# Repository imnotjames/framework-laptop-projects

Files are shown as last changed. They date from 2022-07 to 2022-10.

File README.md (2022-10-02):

# Framework Laptop projects

## eDP port

The framework laptop uses the [I-PEX Cabline-UM 20879-040E-01](https://www.i-pex.com/product/cabline-um)
for interacting with the eDP port - and I want to use it for things other than the framework laptop display kit.

* [Framework eDP 20879-040E-01 Breakout](./breakout/)

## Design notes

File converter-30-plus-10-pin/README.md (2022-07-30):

# Converter for Framework Laptop to 30+10pin 

This converts the framework laptop's 4 lane eDP to the 2 lane used in lower resolution screens.

In particular, this is aimed to allow us to easily interact with the [NV126B5M-N41][amazon] but it's not
exactly tested.

[amazon]: https://www.amazon.com/VSDISPLAY-NV126B5M-N41-12-6inch1920X515-Controller-VS-RTD2556HM-V1/dp/B08FJ33247

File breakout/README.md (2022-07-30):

# Cabline-UM Breakout Board

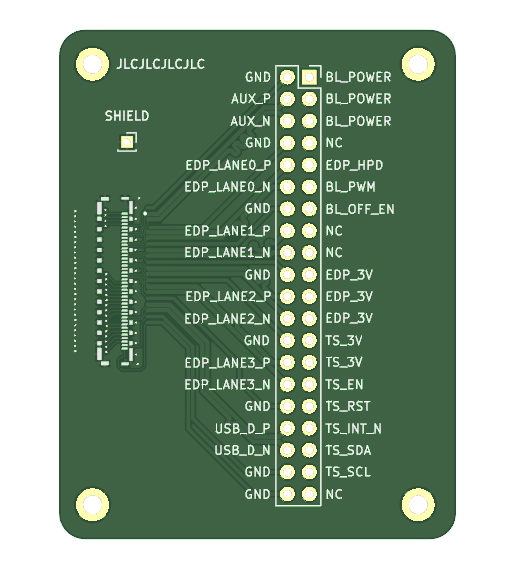
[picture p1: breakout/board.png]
The Breakout Board


This is a breakout board for the Framework Mainboard eDP connection via Cabline-UM 20879-040E-01.

This does not work with the standard Framework laptop cable that comes with the display kit.
The display kit seems to come with a cable that is on one half the cabline-um and on the other half is a cabline-vs
plug.

Instead, this breakout uses the Cabline-UM 20879-040E-01 to connect to the Framework mainboard, allowing you access
to all of the pins in a breakout.

Don't expect to be able to use it for reliable high-speed display-port connections but it may work for
basic prototypes or confirming the touchscreen.

## Fabrication

I've had decent luck getting this fabricated on JLCPCB - it was made with their limitations and tolerances in mind.

## Assembly Hints

If you can figure out how to assemble this by hand with a soldering iron please let me know how!  Most of the pins are hidden
behind a shield so the only way I was able to manage this was with a hot plate and solder paste.

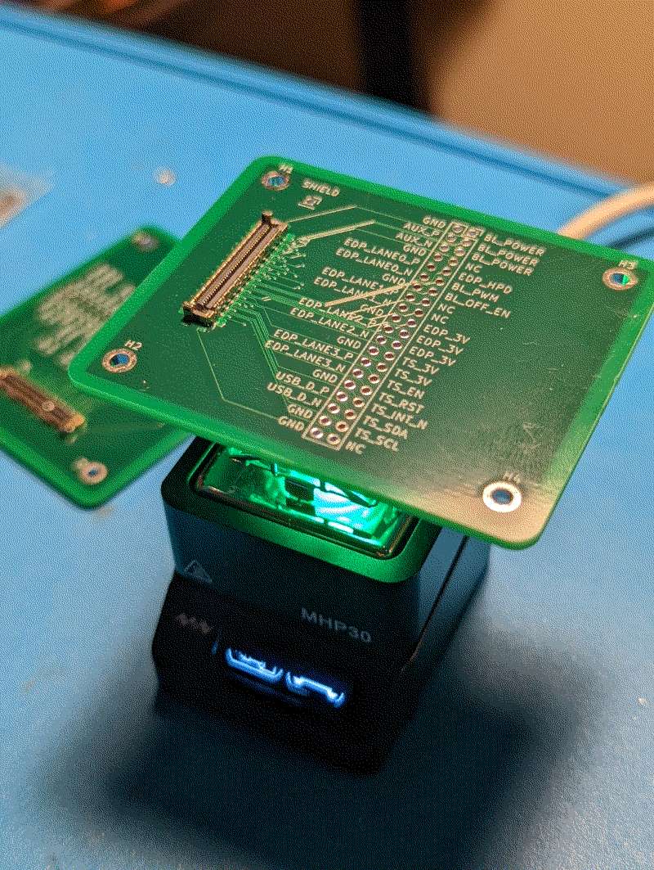
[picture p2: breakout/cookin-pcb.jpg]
Cookin' up some PCB


## Bill of Materials

* [I-PEX 20879-040E-01](https://www.digikey.com/en/products/detail/i-pex/20879-040E-01/14312094)
* [A 40 Position Header Connector with 2.54mm pitch](https://www.digikey.com/en/products/detail/sullins-connector-solutions/PPTC202LFBN-RC/807240)
* [A Cabline-UM plug such as the 81466-100B-02-D](https://www.digikey.com/en/products/detail/i-pex/81466-100B-02-D/14312108)

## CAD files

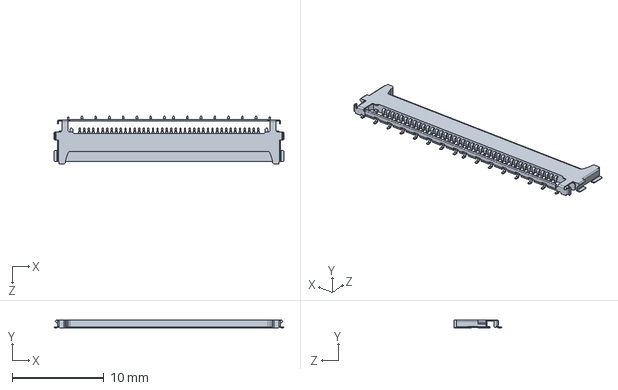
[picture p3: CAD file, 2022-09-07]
converter-30-plus-10-pin/pcb/footprints/20849-040E-01.step
25.1 x 0.82 x 5.20 mm

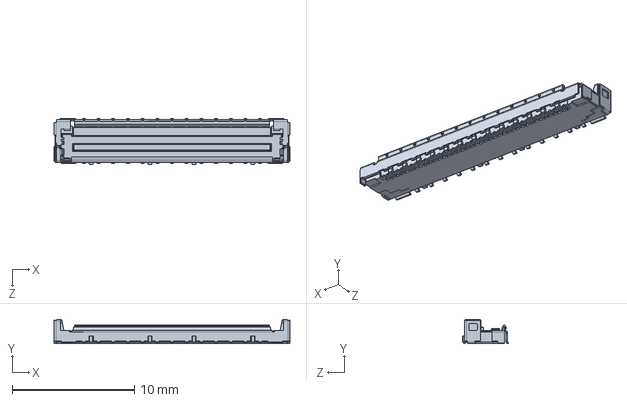
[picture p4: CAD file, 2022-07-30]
converter-30-plus-10-pin/pcb/footprints/20879-040E-01.step
19.3 x 2.00 x 3.77 mm

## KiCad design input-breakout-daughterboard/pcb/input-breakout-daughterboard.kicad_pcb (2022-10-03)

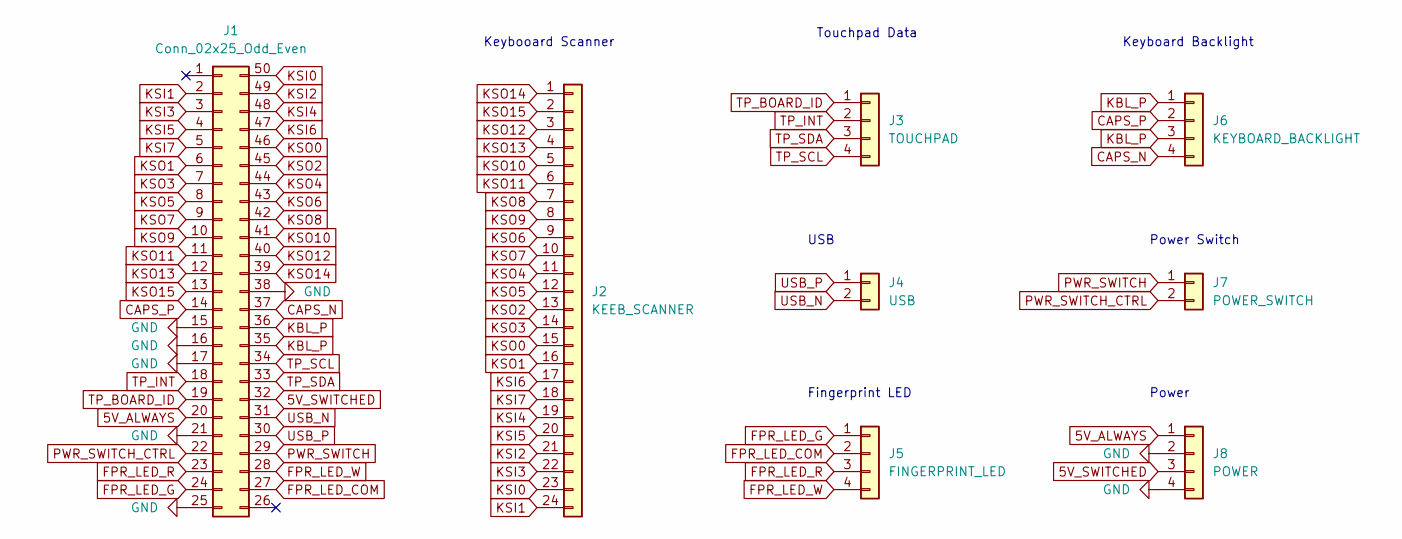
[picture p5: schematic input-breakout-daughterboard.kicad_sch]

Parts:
J1: Conn_02x25_Odd_Even; 10156001-051100LF
J2: KEEB_SCANNER; PinSocket_2x12_P2.54mm_Vertical
J3: TOUCHPAD; PinSocket_2x02_P2.54mm_Vertical
J4: USB; PinSocket_1x02_P2.54mm_Vertical
J5: FINGERPRINT_LED; PinSocket_2x02_P2.54mm_Vertical
J6: KEYBOARD_BACKLIGHT; PinSocket_2x02_P2.54mm_Vertical
J7: POWER_SWITCH; PinSocket_1x02_P2.54mm_Vertical
J8: POWER; PinSocket_2x02_P2.54mm_Vertical

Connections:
5V_ALWAYS: J1.20, J8.1
5V_SWITCHED: J1.32, J8.3
CAPS_N: J1.37, J6.4
CAPS_P: J1.14, J6.2
FPR_LED_COM: J1.27, J5.2
FPR_LED_G: J1.24, J5.1
FPR_LED_R: J1.23, J5.3
FPR_LED_W: J1.28, J5.4
GND: J1.15, J1.16, J1.17, J1.21, J1.25, J1.38, J8.2, J8.4
KBL_P: J1.35, J1.36, J6.1, J6.3
KSI0: J1.50, J2.23
KSI1: J1.2, J2.24
KSI2: J1.49, J2.21
KSI3: J1.3, J2.22
KSI4: J1.48, J2.19
KSI5: J1.4, J2.20
KSI6: J1.47, J2.17
KSI7: J1.5, J2.18
KSO0: J1.46, J2.15
KSO1: J1.6, J2.16
KSO2: J1.45, J2.13
KSO3: J1.7, J2.14
KSO4: J1.44, J2.11
KSO5: J1.8, J2.12
KSO6: J1.43, J2.9
KSO7: J1.9, J2.10
KSO8: J1.42, J2.7
KSO9: J1.10, J2.8
KSO10: J1.41, J2.5
KSO11: J1.11, J2.6
KSO12: J1.40, J2.3
KSO13: J1.12, J2.4
KSO14: J1.39, J2.1
KSO15: J1.13, J2.2
PWR_SWITCH: J1.29, J7.1
PWR_SWITCH_CTRL: J1.22, J7.2
TP_BOARD_ID: J1.19, J3.1
TP_INT: J1.18, J3.2
TP_SCL: J1.34, J3.4
TP_SDA: J1.33, J3.3
USB_N: J1.31, J4.2
USB_P: J1.30, J4.1

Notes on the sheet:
Power
Touchpad Data
USB
Keybooard Scanner
Keyboard Backlight
Power Switch
Fingerprint LED

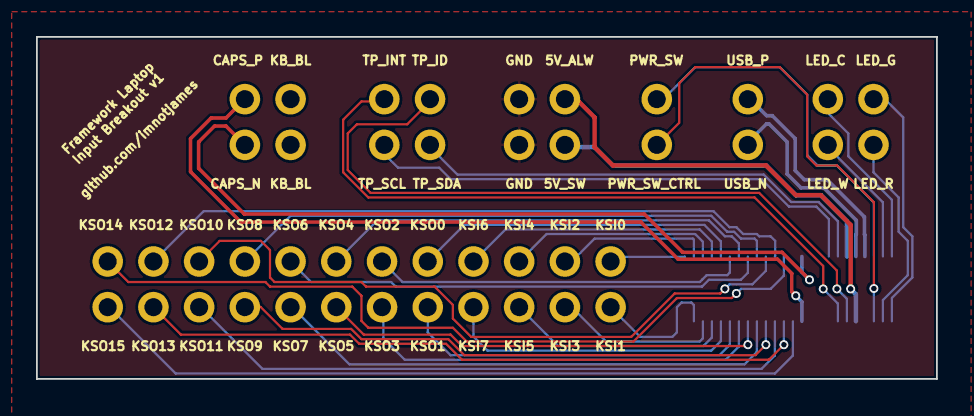
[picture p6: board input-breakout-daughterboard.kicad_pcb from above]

Board: 2 copper layers, 50.0 x 19.0 mm, 8 parts (1 on the bottom side), 42 nets.

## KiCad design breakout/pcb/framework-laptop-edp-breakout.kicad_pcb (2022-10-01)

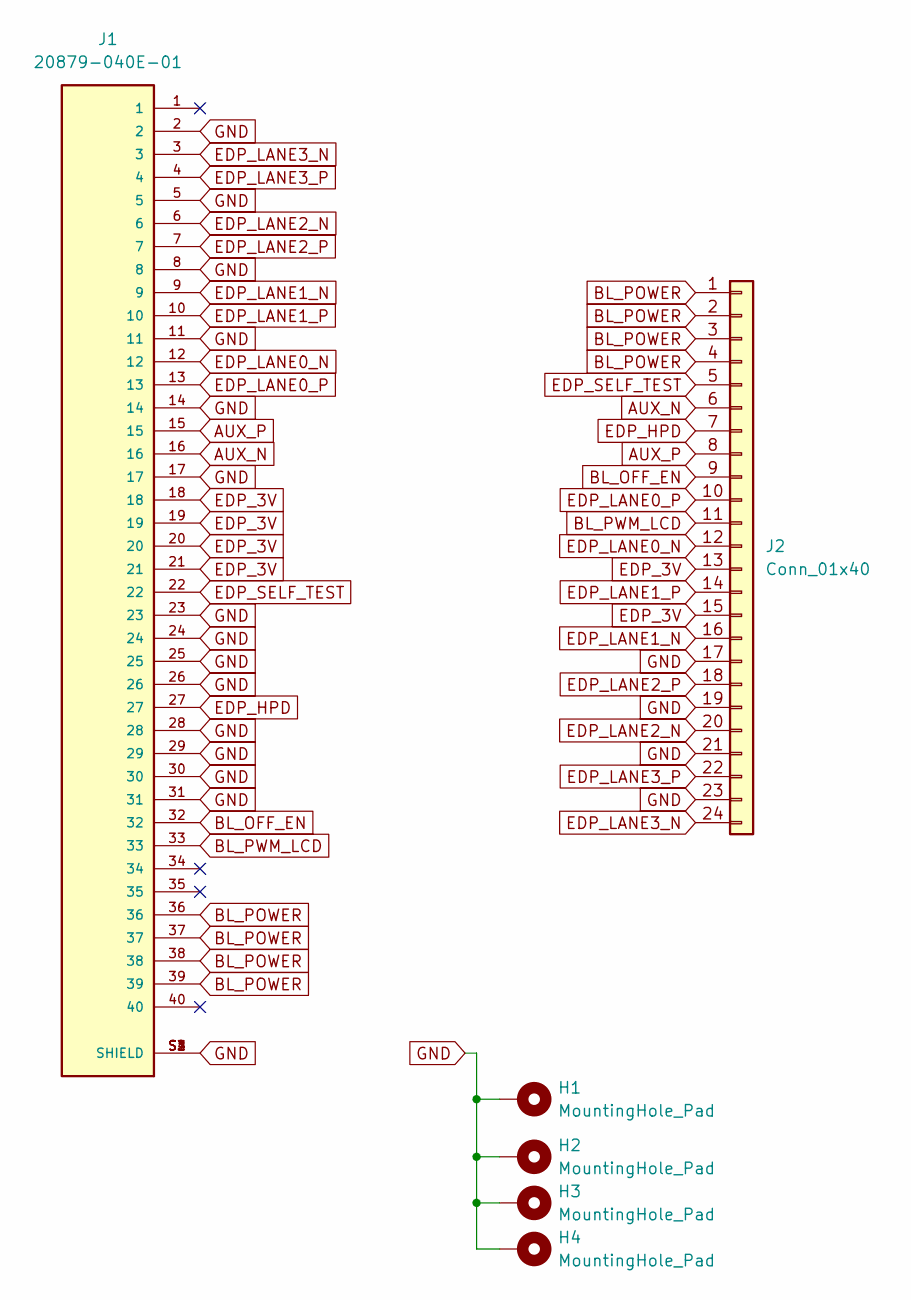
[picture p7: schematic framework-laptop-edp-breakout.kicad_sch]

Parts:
H1, H2, H3, H4: MountingHole_Pad; MountingHole_2.2mm_M2_DIN965_Pad
J1: 20879-040E-01; IPEX_20455-040E-76; PARTREV 11
J2: Conn_01x40; PinSocket_2x12_P2.54mm_Vertical

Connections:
AUX_N: J1.16, J2.6
AUX_P: J1.15, J2.8
BL_OFF_EN: J1.32, J2.9
BL_POWER: J1.36, J1.37, J1.38, J1.39, J2.1, J2.2, J2.3, J2.4
BL_PWM_LCD: J1.33, J2.11
EDP_3V: J1.18, J1.19, J1.20, J1.21, J2.13, J2.15
EDP_HPD: J1.27, J2.7
EDP_LANE0_N: J1.12, J2.12
EDP_LANE0_P: J1.13, J2.10
EDP_LANE1_N: J1.9, J2.16
EDP_LANE1_P: J1.10, J2.14
EDP_LANE2_N: J1.6, J2.20
EDP_LANE2_P: J1.7, J2.18
EDP_LANE3_N: J1.3, J2.24
EDP_LANE3_P: J1.4, J2.22
EDP_SELF_TEST: J1.22, J2.5
GND: H1.1, H2.1, H3.1, H4.1, J1.2, J1.5, J1.8, J1.11, J1.14, J1.17, J1.23, J1.24, J1.25, J1.26, J1.28, J1.29, J1.30, J1.31, J1.S1 (SHIELD), J1.S2 (SHIELD), J1.S3 (SHIELD), J1.S4 (SHIELD), J2.17, J2.19, J2.21, J2.23

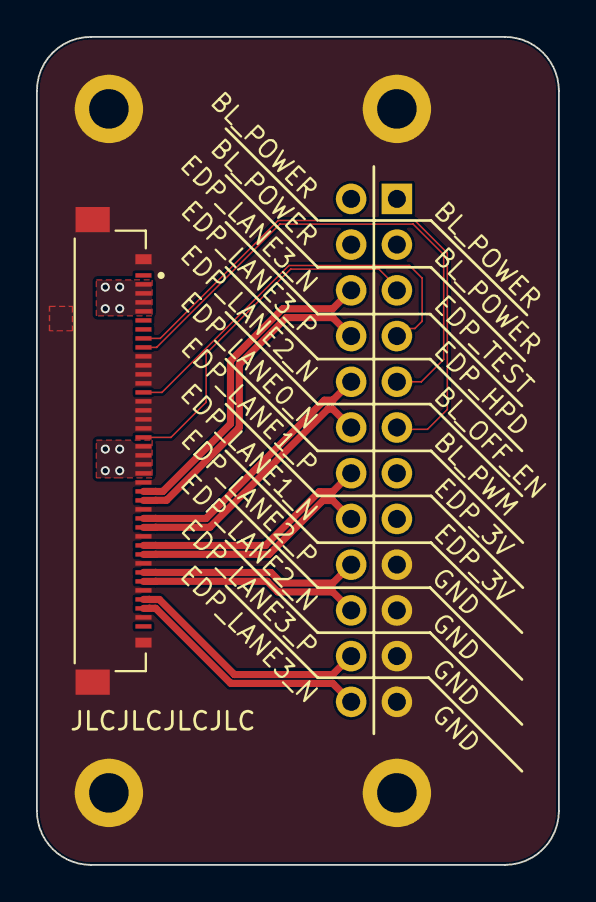
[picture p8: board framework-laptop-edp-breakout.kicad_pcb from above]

Board: 2 copper layers, 29.0 x 46.0 mm, 6 parts (0 on the bottom side), 17 nets.

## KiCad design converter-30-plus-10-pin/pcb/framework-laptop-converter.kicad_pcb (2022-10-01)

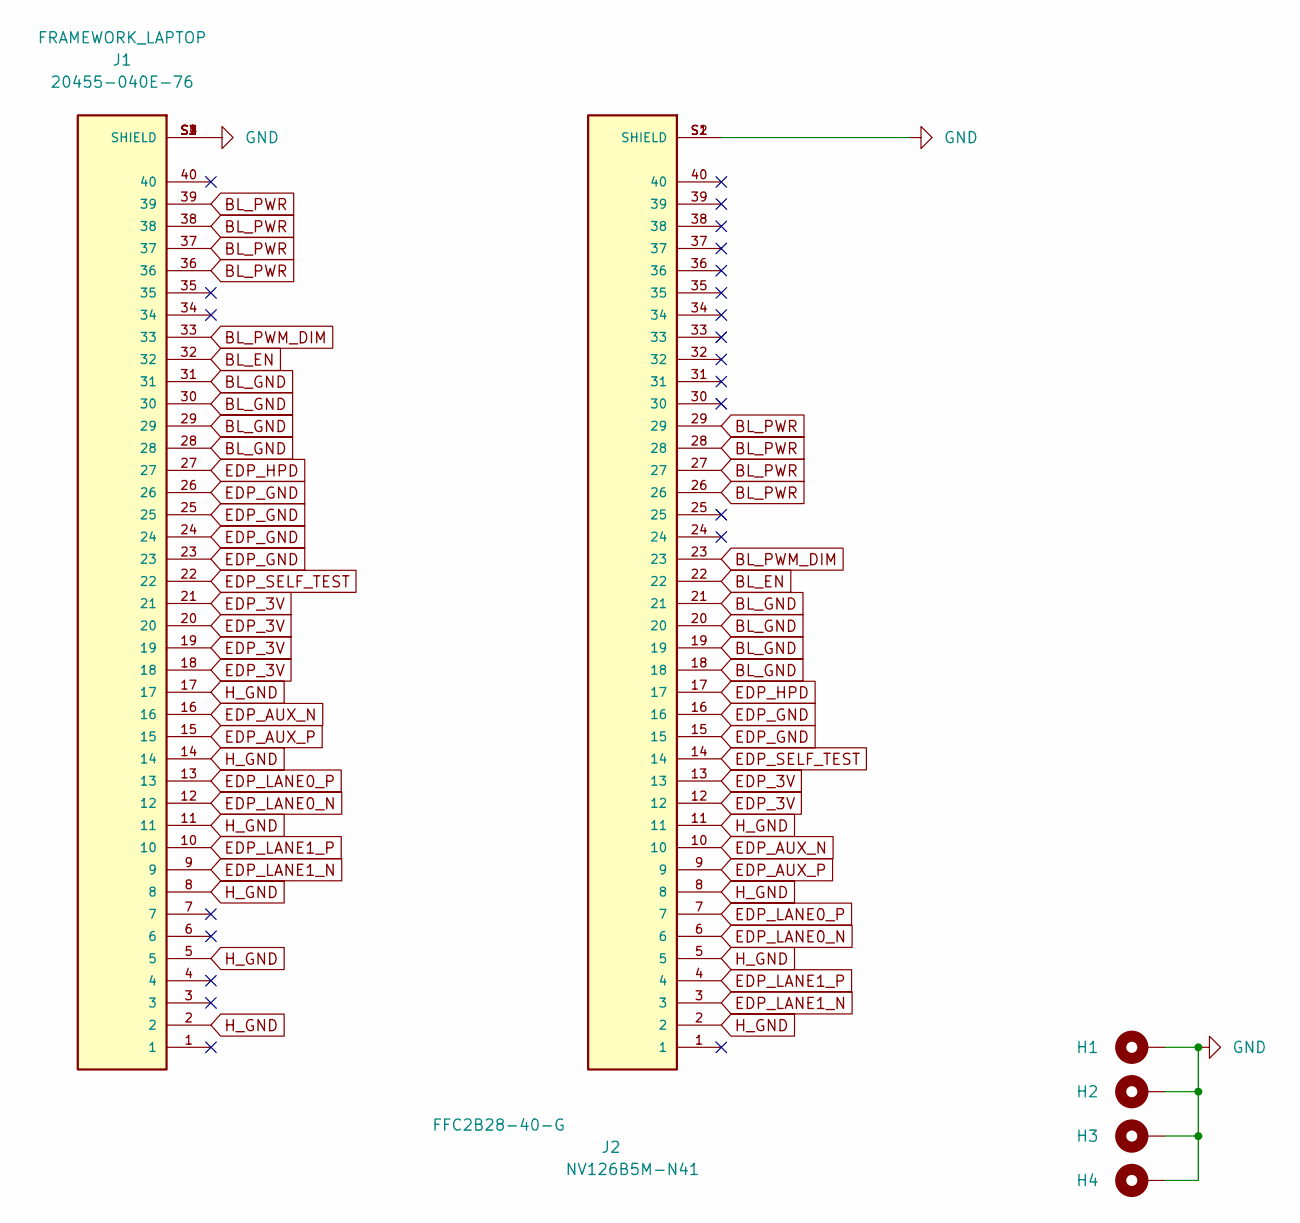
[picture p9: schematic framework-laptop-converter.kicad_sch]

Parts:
H1, H2, H3, H4: MountingHole_Pad; MountingHole_2.2mm_M2_Pad
J1: 20455-040E-76; IPEX_20455-040E-76; PARTREV 11
J2: FFC2B28-40-G; GCT_FFC2B28-40-G; PARTREV A

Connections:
BL_EN: J1.32, J2.22
BL_GND: J1.28, J1.29, J1.30, J1.31, J2.18, J2.19, J2.20, J2.21
BL_PWM_DIM: J1.33, J2.23
BL_PWR: J1.36, J1.37, J1.38, J1.39, J2.26, J2.27, J2.28, J2.29
EDP_3V: J1.18, J1.19, J1.20, J1.21, J2.12, J2.13
EDP_AUX_N: J1.16, J2.10
EDP_AUX_P: J1.15, J2.9
EDP_GND: J1.23, J1.24, J1.25, J1.26, J2.15, J2.16
EDP_HPD: J1.27, J2.17
EDP_LANE0_N: J1.12, J2.6
EDP_LANE0_P: J1.13, J2.7
EDP_LANE1_N: J1.9, J2.3
EDP_LANE1_P: J1.10, J2.4
EDP_SELF_TEST: J1.22, J2.14
GND: H1.1, H2.1, H3.1, H4.1, J1.S1 (SHIELD), J1.S2 (SHIELD), J1.S3 (SHIELD), J1.S4 (SHIELD), J2.S1 (SHIELD), J2.S2 (SHIELD)
H_GND: J1.2, J1.5, J1.8, J1.11, J1.14, J1.17, J2.2, J2.5, J2.8, J2.11

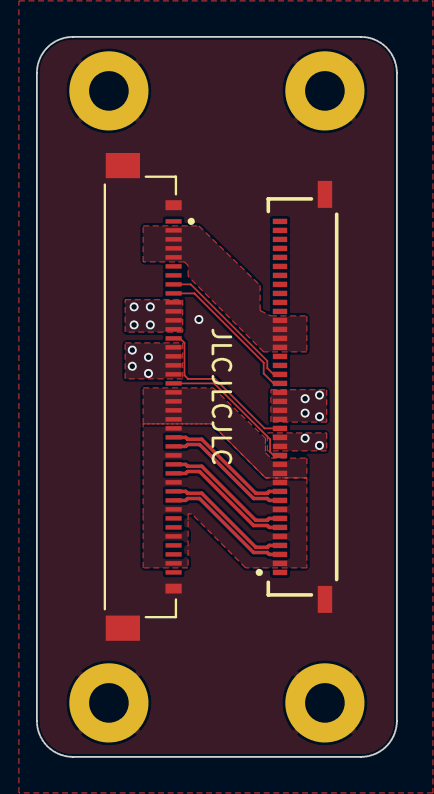
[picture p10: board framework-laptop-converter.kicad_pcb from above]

Board: 2 copper layers, 20.0 x 40.0 mm, 6 parts (0 on the bottom side), 16 nets.

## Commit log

2022-07-30 better length matching
    I mean, impedance for a breakout seems kinda silly but it's worth it for learning, right?
    [framework-laptop-edp-breakout.kicad_pcb]
2022-07-30 add a converter that maybe works maybe not
    [20879-040E-01.step, framework-laptop-converter.kicad_pcb, framework-laptop-converter.kicad_sch]
2022-08-01 fewer slots so this can be fabbed cheaper
    [framework-laptop-converter.kicad_pcb]
2022-08-16 rework breakout because pins were wrong
    turns out pin out documentation from framework is reversed - pin 40 in pinouts.md is pin 1 on the data sheet for the ipex connector
    [framework-laptop-edp-breakout.kicad_pcb, framework-laptop-edp-breakout.kicad_sch]
2022-08-16 fix breakout labels on back
    [framework-laptop-edp-breakout.kicad_pcb]
2022-08-16 finish up routing on breakout
    [framework-laptop-edp-breakout.kicad_pcb]
2022-08-17 start migrating converter to framework's true pinout
    [framework-laptop-converter.kicad_pcb, framework-laptop-converter.kicad_sch]
2022-08-17 converter: route edp lane 0 and aux + fix shield to ground
    [framework-laptop-converter.kicad_pcb, framework-laptop-converter.kicad_sch]
2022-08-17 finish up edp converter with edp lane
    [framework-laptop-converter.kicad_pcb]
2022-08-17 hide converter connector IDs
    [framework-laptop-converter.kicad_pcb]
2022-08-18 mark converter as v4
    [framework-laptop-converter.kicad_pcb]
2022-08-18 breakout v4
    [framework-laptop-edp-breakout.kicad_pcb]
2022-08-19 bigger vias so jlcpcb gets off my case
    [framework-laptop-converter.kicad_pcb]
2022-08-19 bigger vias on the breakout & remove some of em
    [framework-laptop-edp-breakout.kicad_pcb]
2022-08-19 improve power rails on the breakout
    [framework-laptop-edp-breakout.kicad_pcb]
2022-08-19 another via on bl_power in the breakout
    [framework-laptop-edp-breakout.kicad_pcb]
2022-08-19 converter was crooked
    [framework-laptop-converter.kicad_pcb]
2022-08-19 fix dimensions on converter
    [framework-laptop-converter.kicad_pcb]
2022-09-07 redo converter to use the 20455-040E
    [20849-040E-01.step, framework-laptop-converter.kicad_pcb, framework-laptop-converter.kicad_sch]
2022-09-07 larger vias
    [framework-laptop-converter.kicad_pcb]
2022-09-07 clean up footprints & connections
    [framework-laptop-converter.kicad_sch]
2022-09-16 for some reason these are backwards too
    [framework-laptop-converter.kicad_pcb]
2022-09-16 make breakout use the bundled cable
    [framework-laptop-edp-breakout.kicad_pcb, framework-laptop-edp-breakout.kicad_sch]
2022-09-16 migrate breakout to new connector I guess
    [framework-laptop-edp-breakout.kicad_pcb, framework-laptop-edp-breakout.kicad_sch]
2022-09-16 bump converter rev number
    [framework-laptop-converter.kicad_pcb]
2022-09-25 when you rush you make mistakes
    [framework-laptop-edp-breakout.kicad_pcb]
2022-10-01 clean up converter to 2 layers & attach the BL_EN
    [framework-laptop-converter.kicad_pcb, framework-laptop-converter.kicad_sch]
2022-10-01 add revision to the breakout because I'm losing track
    [framework-laptop-edp-breakout.kicad_pcb]
2022-10-02 start toying with a breakout board for the input connector
    [input-breakout-daughterboard.kicad_pcb, input-breakout-daughterboard.kicad_sch]
2022-10-03 input seems good enough for a v1
    [input-breakout-daughterboard.kicad_pcb, input-breakout-daughterboard.kicad_sch]
